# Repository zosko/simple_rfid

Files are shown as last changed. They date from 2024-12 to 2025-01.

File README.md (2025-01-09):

# simple-rfid
Arduino 125Khz RFID emulator / cloner / reader 

Components:
- RFID Reader RMD6300
- Arduino Nano

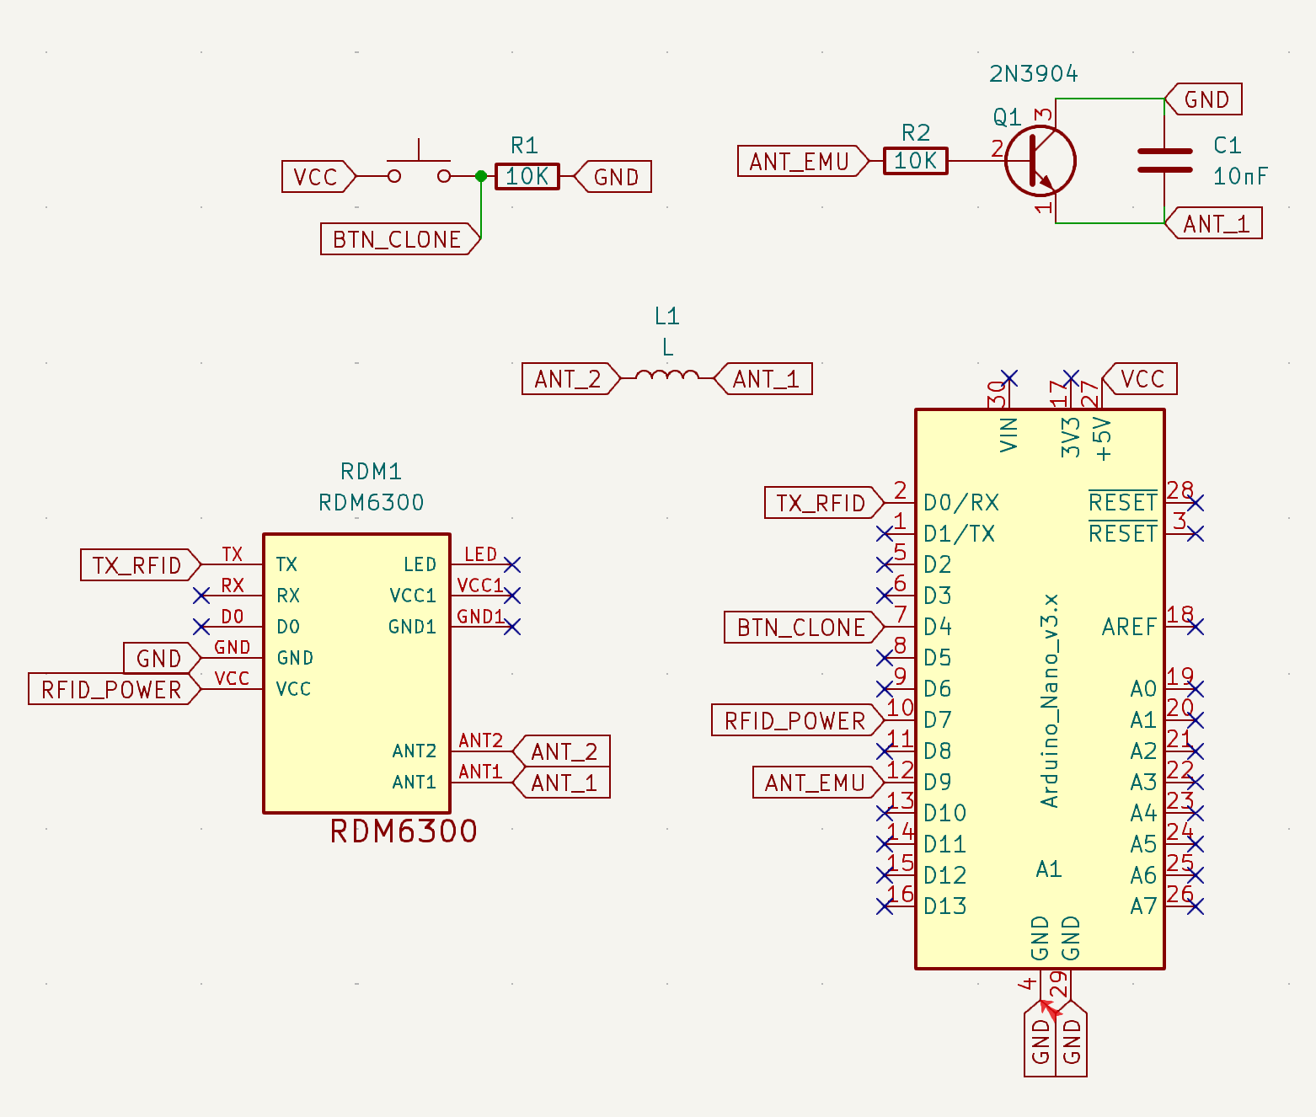
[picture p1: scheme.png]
scheme


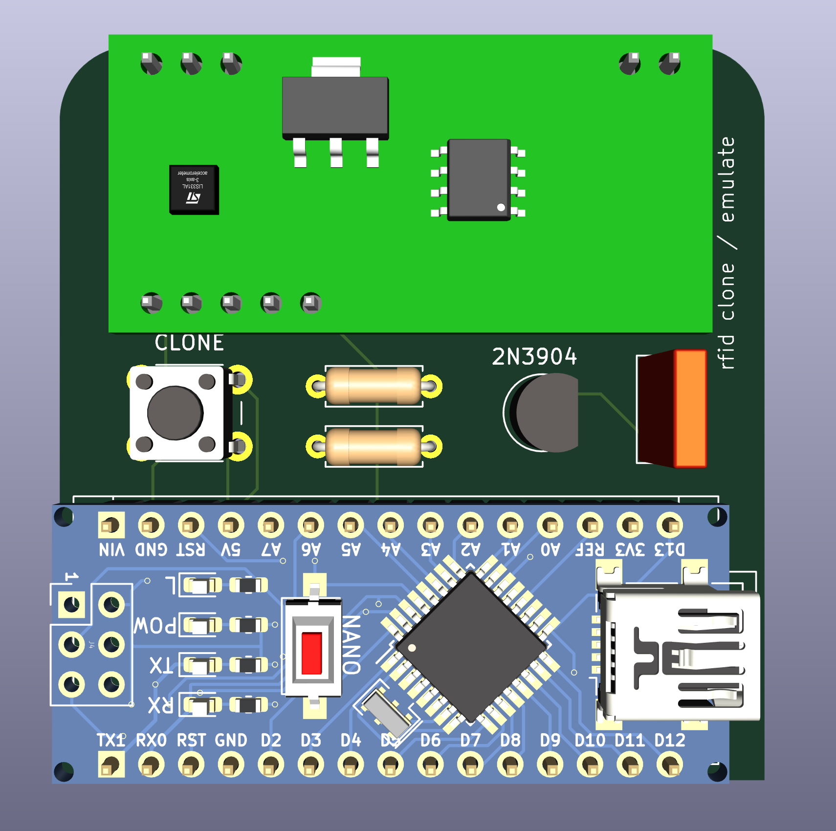
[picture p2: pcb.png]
pcb


## Sponsorship

PCBWay_logo

This project is kindly sponsored by [PCBWay](https://pcbway.com).
PCBWay specializes in manufacturing high-quality PCBs and makes them affordable to hobbyist and professionals alike.

The range of services they offer include PCB prototyping, assembly, instant quotes for your order, a verification process by a team
of experts and an easy to use, hassle-free order process.

I'm grateful to PCBWay for the support in creating this project.

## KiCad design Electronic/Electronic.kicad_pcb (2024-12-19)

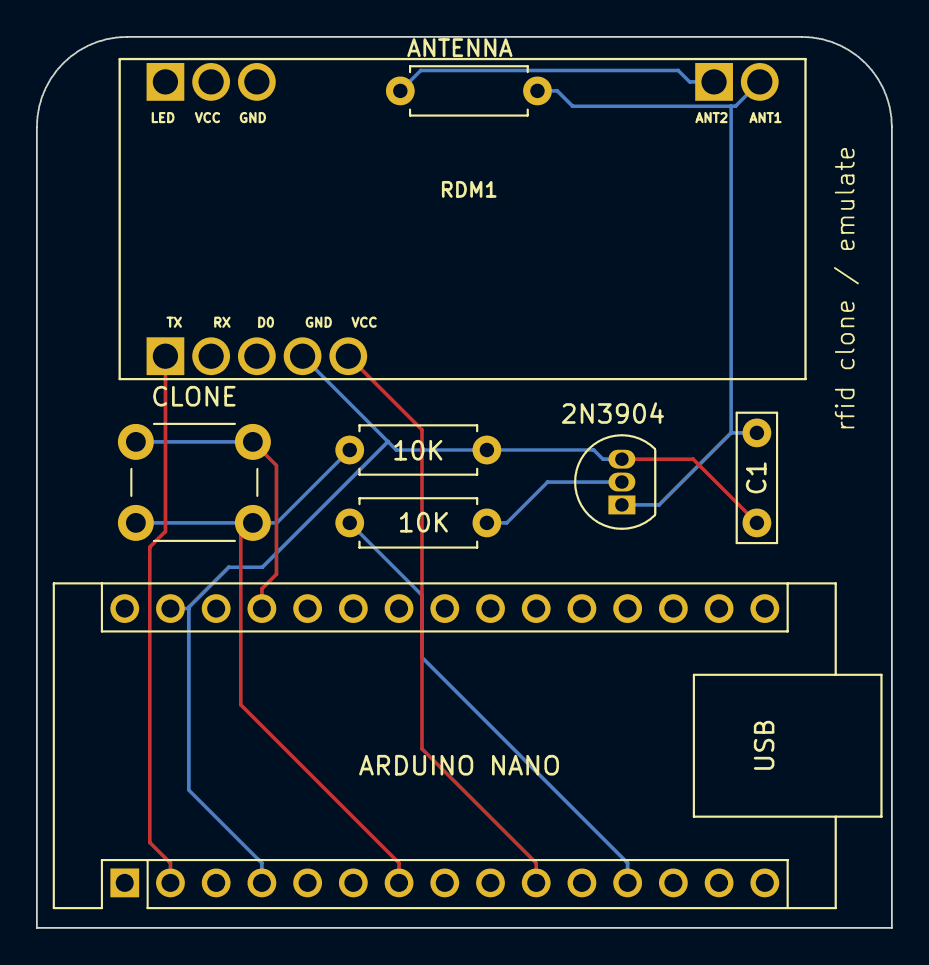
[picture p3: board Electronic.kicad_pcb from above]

Board: 2 copper layers, 47.5 x 49.5 mm, 8 parts (0 on the bottom side), 9 nets.

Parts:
2N3904: 2N3904; TO-92_Inline
10K, 10K#2: 10K; R_Axial_DIN0207_L6.3mm_D2.5mm_P7.62mm_Horizontal
ANTENNA: L; R_Axial_DIN0207_L6.3mm_D2.5mm_P7.62mm_Horizontal
ARDUINO NANO: Arduino_Nano_v3.x; Arduino_Nano
C1: 10nF; C_Rect_L7.0mm_W2.0mm_P5.00mm
CLONE: SW_Push; SW_PUSH_6mm
RDM1: RDM6300

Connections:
ANT_1: 2N3904.1 (E), ANTENNA.2, C1.2, RDM1.ANT1
ANT_2: ANTENNA.1, RDM1.ANT2
ANT_EMU: 10K#2.1, ARDUINO NANO.12 (D9)
BTN_CLONE: 10K.1, ARDUINO NANO.7 (D4), CLONE.2
GND: 2N3904.3 (C), 10K.2, ARDUINO NANO.4 (GND), ARDUINO NANO.29 (GND), C1.1, RDM1.GND
unnamed: 2N3904.2 (B), 10K#2.2
RFID_POWER: ARDUINO NANO.10 (D7), RDM1.VCC
TX_RFID: ARDUINO NANO.2 (D0/RX), RDM1.TX
VCC: ARDUINO NANO.27 (+5V), CLONE.1

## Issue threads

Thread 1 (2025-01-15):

Question

AllinolCP, 2025-01-15:
Hi there, it seems that in the schematic ANT1 is connected to GND and the transistor. Was this intentional?
I have tried this circuit in my setup and the RDM630 just stopped reading cards afterwards

AllinolCP, 2025-01-16:
Nevermind the updated schematic is fixed it now.

zosko, 2025-01-22:
Cool :) , yea in old schematic that was wrong, now should is easy for reading and is working too as before.

Closed 2025-01-16.

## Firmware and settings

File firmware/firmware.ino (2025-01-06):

#include <EEPROM.h>

// MEMORY
int LAST_CARD_USED = 100;

// PINS
int BUTTON_CLONE_CARD = 4;
int POWER_READER = 7;
int COIL_PIN = 9;

// EMULATION
uint32_t card_generated;

// RDM6300
bool id_is_valid = false;
unsigned long long current_id;
unsigned char received_checksum;

void setup() {
  Serial.begin(9600);

  intro();

  pinMode(BUTTON_CLONE_CARD, INPUT);
  pinMode(POWER_READER, OUTPUT);
  pinMode(COIL_PIN, OUTPUT);
  pinMode(LED_BUILTIN, OUTPUT);

  digitalWrite(COIL_PIN, LOW);

  delay(1000);
}
void loop() {

  bool buttonMenuPressed = digitalRead(BUTTON_CLONE_CARD) == HIGH;

  if (buttonMenuPressed) {
    digitalWrite(LED_BUILTIN, HIGH);
    if (Serial.available()) {
      char command = Serial.read();
      if (command == 'l') {
        list();
      }
      if (command == 'c') {
        clear();
      }

      digitalWrite(LED_BUILTIN, LOW);
    } else {
      int lastSavedLocation = EEPROMReadlong(LAST_CARD_USED);
      bool isCloned = cloneCard(lastSavedLocation);
      if (isCloned) {
        lastSavedLocation++;
        if (lastSavedLocation > 4) {
          lastSavedLocation = 4;
        }
        EEPROMWritelong(LAST_CARD_USED, lastSavedLocation);

        for (int i = 0; i < 5; i++) {
          digitalWrite(LED_BUILTIN, HIGH);
          delay(300);
          digitalWrite(LED_BUILTIN, LOW);
          delay(300);
        }
      }
    }
  }

  for (int i = 0; i < 5; i++) {

    uint64_t card_id = EEPROMReadlong(i * 10);
    card_generated = generate_card(card_id);

    for (int y = 0; y < 10; y++) {
      emulateCard(card_generated);
    }
  }
}

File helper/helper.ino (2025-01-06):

#include <EEPROM.h>

uint64_t EEPROMReadlong(int address) {
  uint64_t card = 0;
  for (int i = address, b = 0; i < address + 10; i++, b++) {
    uint64_t tmp = EEPROM.read(i);
    tmp = tmp << (36 - b * 4);
    card |= tmp;
  }
  return card;
}

void print_int64(char *text, unsigned long long data) {
  Serial.print(text);
  union {
    unsigned long long ull;
    unsigned long ul[2];
  } tmp;
  tmp.ull = data;
  Serial.print(tmp.ul[1], HEX);
  unsigned long beacon = 0x10000000;
  while (beacon > 0) {
    if (tmp.ul[0] < beacon)
      Serial.print("0");
    else
      break;
    beacon >>= 4;
  }
  Serial.println(tmp.ul[0], HEX);
}

void setup() {
  Serial.begin(9600);

  Serial.println("COMMANDS: ");
  Serial.println("    'l' - list saved cards");
  Serial.println("    'c' - clear saved cards");
}

void clear() {
  Serial.print("EEPROM CLEARING....");
  for (int i = 0; i < EEPROM.length(); i++) {
    EEPROM.write(i, 0);
  }
  Serial.print("EEPROM CLEAR!");
}

void list() {
  int card_selected = EEPROMReadlong(100);
  Serial.print("LAST CARD USED: ");
  Serial.println(card_selected);

  for (int i = 0; i < 5; i++) {
    Serial.print("ID [");
    Serial.print(i);
    Serial.print("] : ");
    uint64_t card_id = EEPROMReadlong(i * 10);
    print_int64("EMULATE CARD: ", card_id);
  }
}

void loop() {
  if (Serial.available()) {
    char command = Serial.read();
    if (command == 'l') {
      list();
    }
    if (command == 'c') {
      clear();
    }
  }
}
